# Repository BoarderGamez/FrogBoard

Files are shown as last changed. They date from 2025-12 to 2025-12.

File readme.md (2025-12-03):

# FrogBoard
My own devboard, from keyboard, to devboard 👍






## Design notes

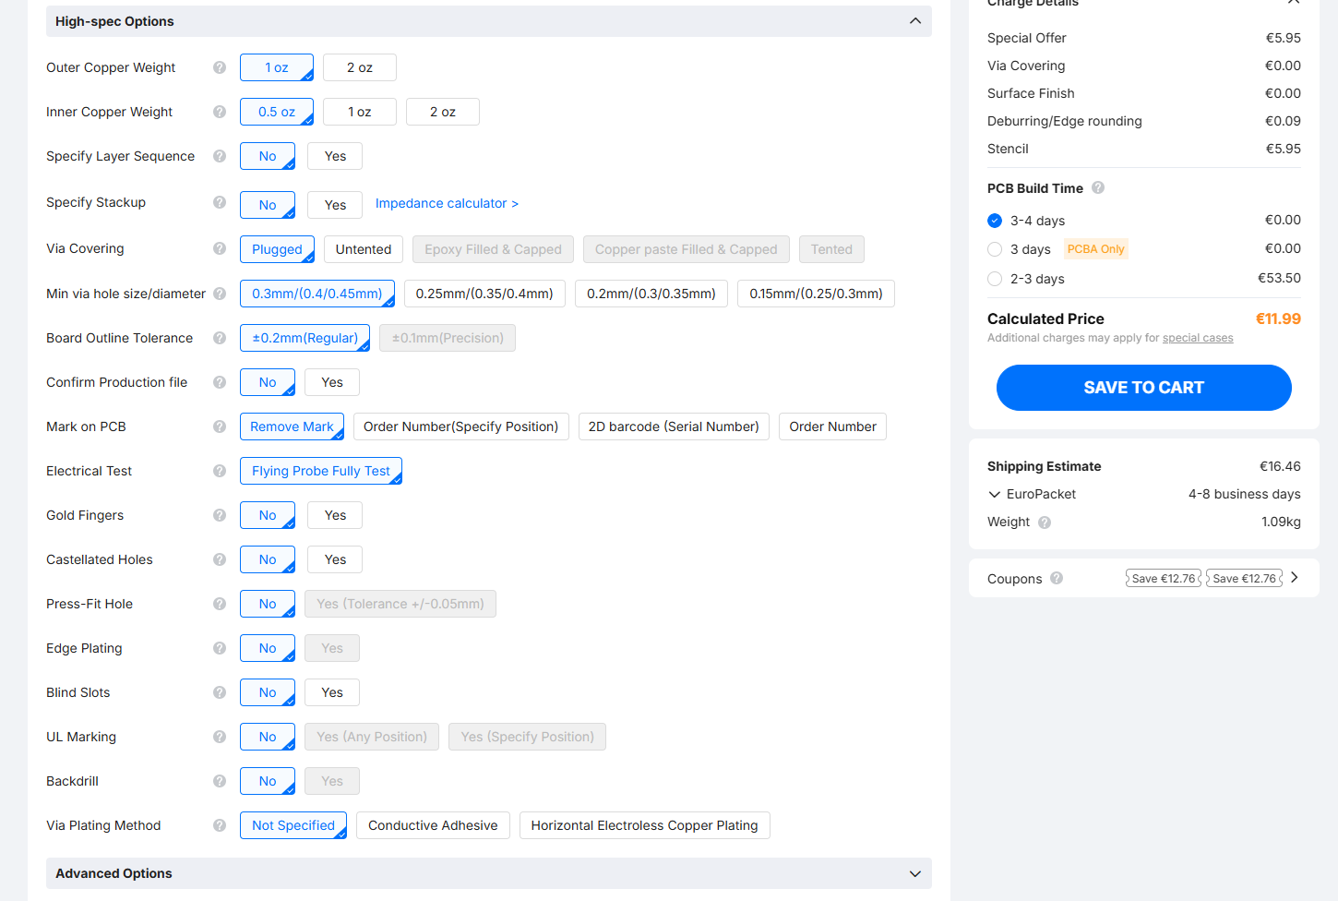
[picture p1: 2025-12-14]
pics/Screenshot 2025-12-14 181616.png

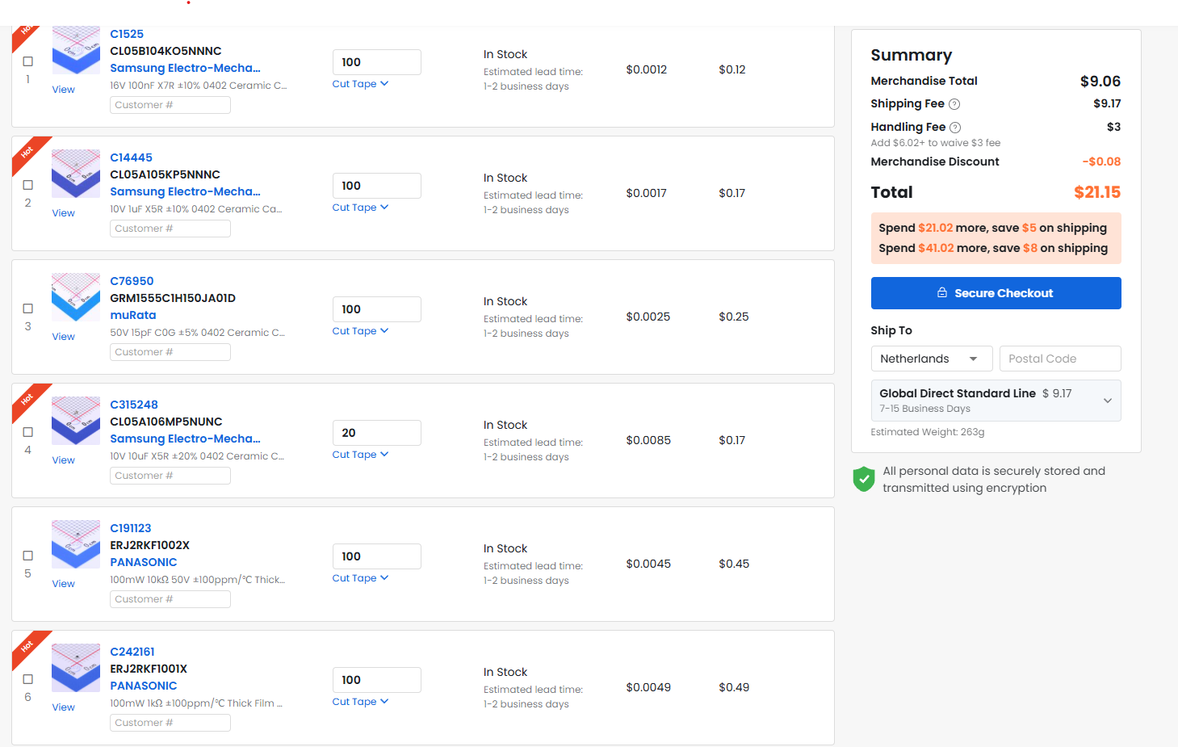
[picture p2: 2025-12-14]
pics/Screenshot 2025-12-14 181058.png

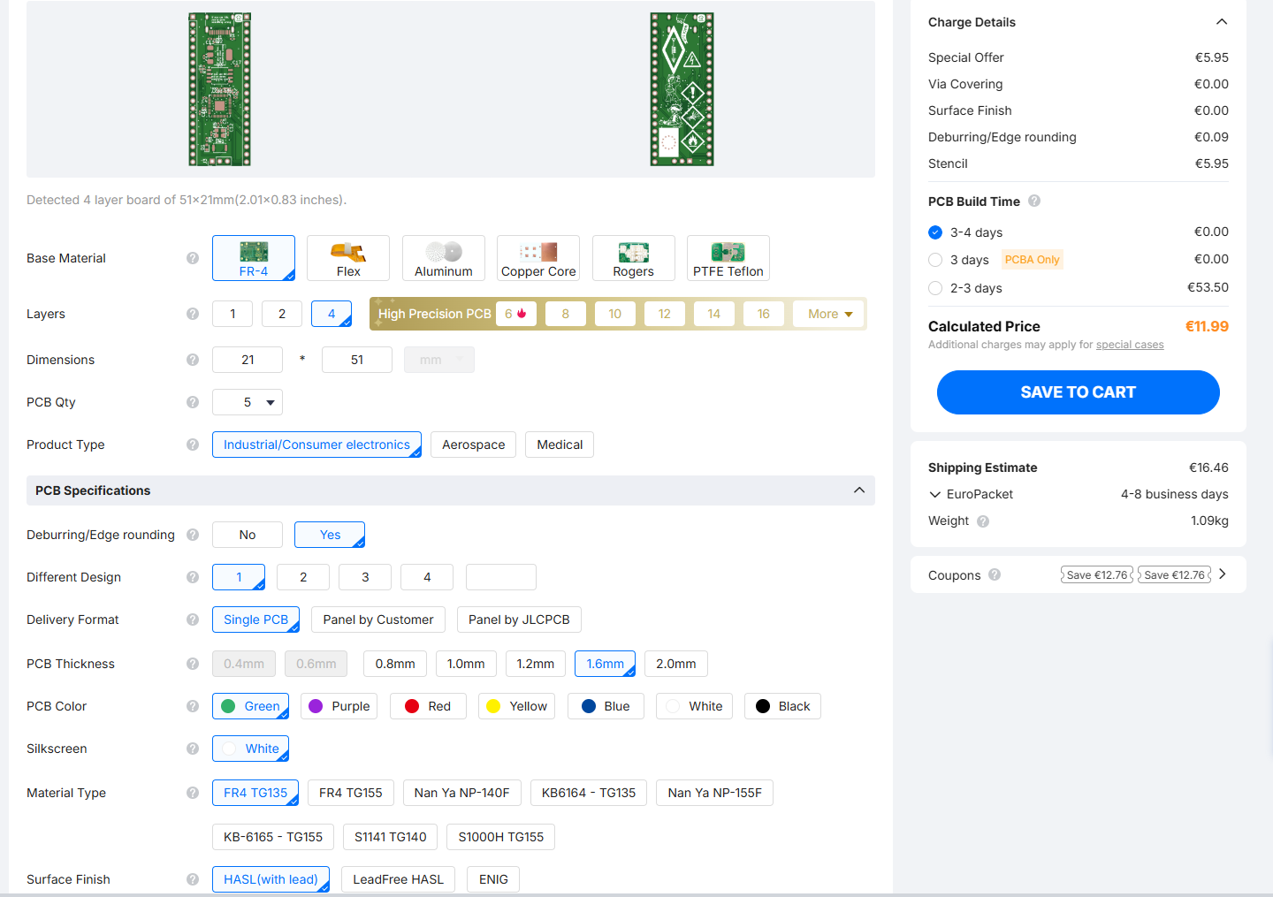
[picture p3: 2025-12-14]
pics/Screenshot 2025-12-14 181558.png

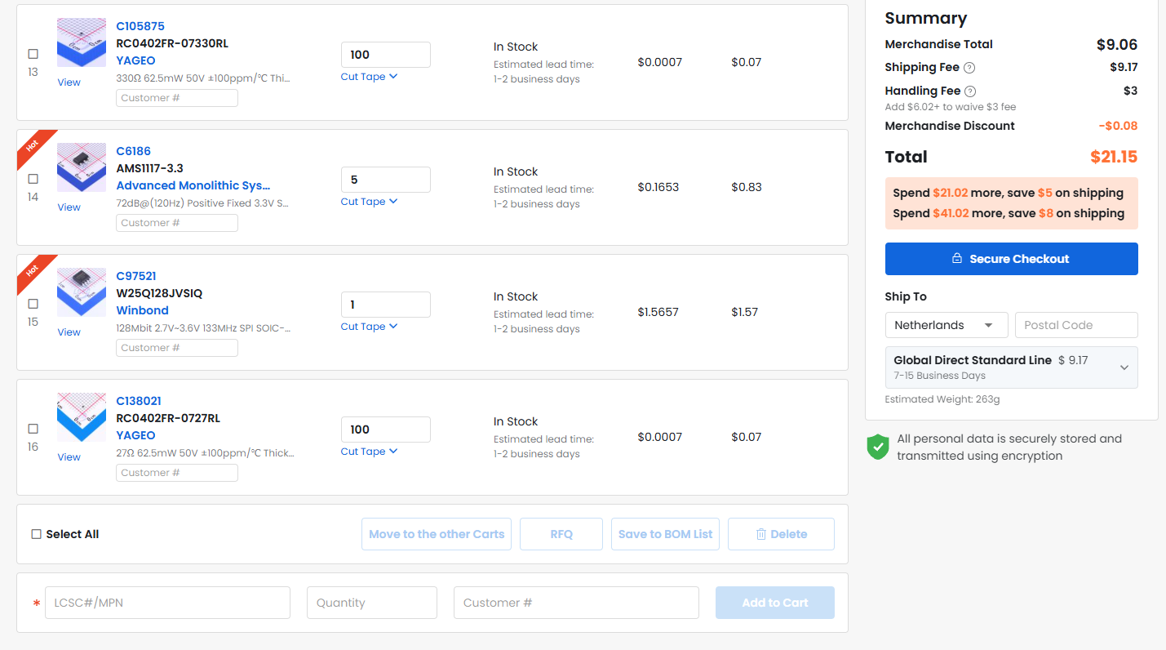
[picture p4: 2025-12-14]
pics/Screenshot 2025-12-14 181120.png

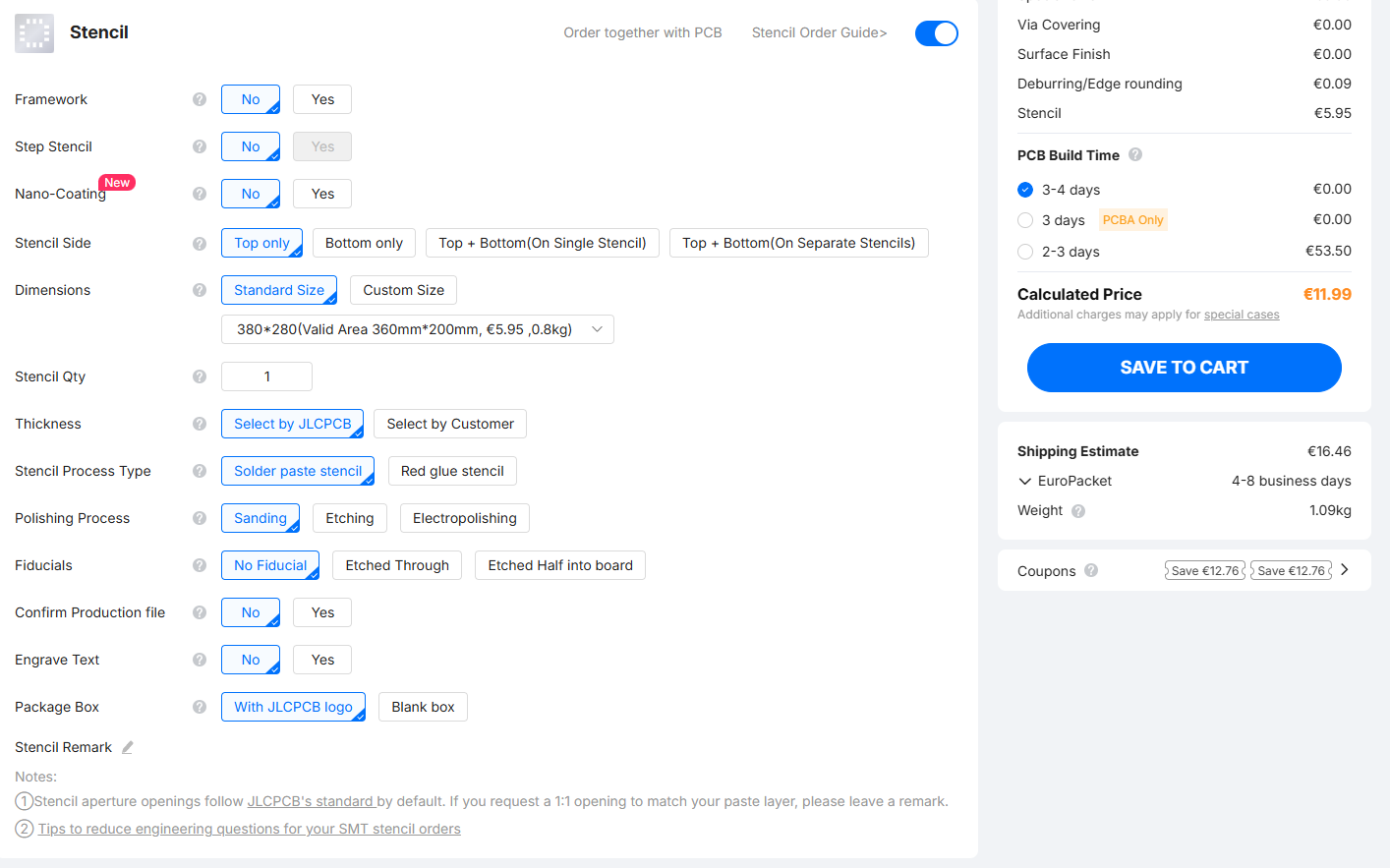
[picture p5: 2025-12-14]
pics/Screenshot 2025-12-14 181629.png

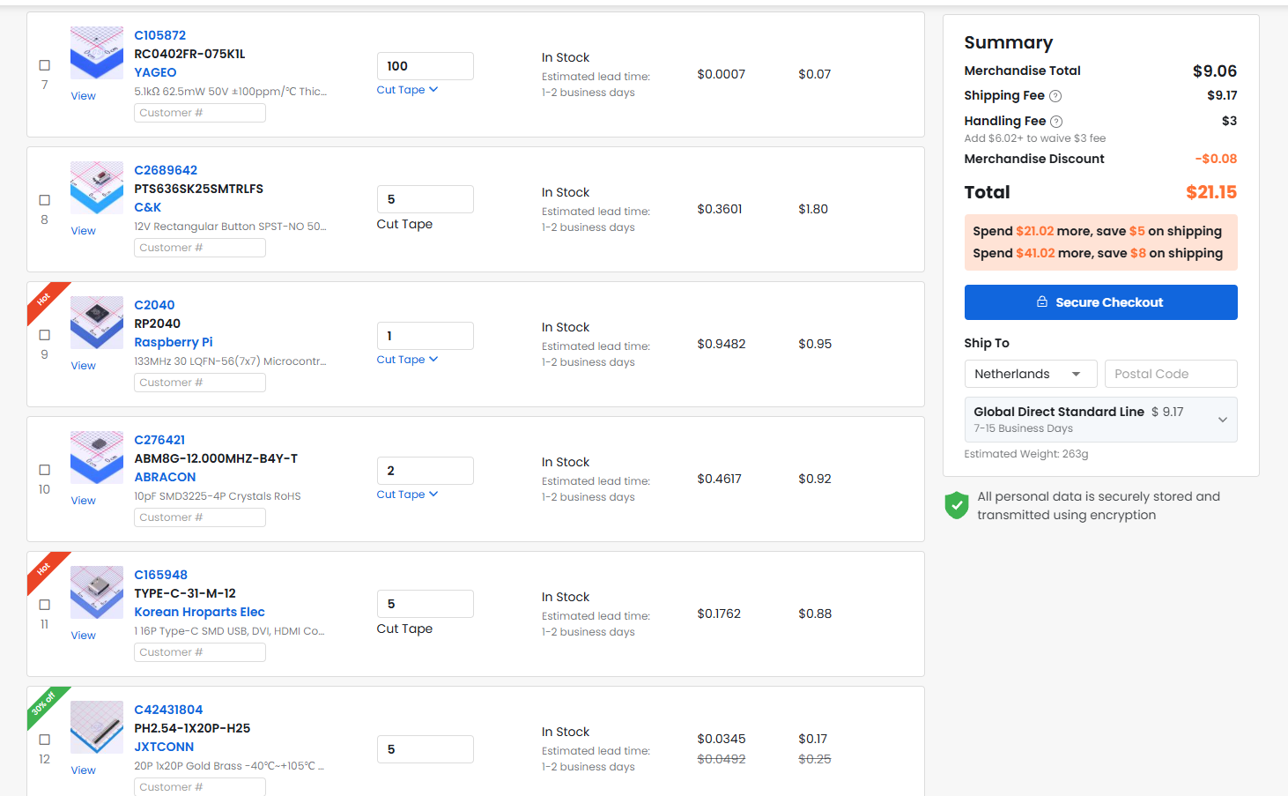
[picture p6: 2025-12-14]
pics/Screenshot 2025-12-14 181109.png

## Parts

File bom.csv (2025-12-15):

Index | LCSC# | MPN | Manufacturer | Package | Customer # | Description | RoHS | Quantity | MOQ | Multiple | Unit Price($) | Extended Price($) | Product Link | Total
1 | C1525 | CL05B104KO5NNNC | Samsung Electro-Mechanics | 0402 |  | 16V 100nF X7R ±10% 0402 Ceramic Capacitors RoHS | yes | 100 | 100 | 100 | 0.0012 | 0.12 | https://www.lcsc.com/product-detail/C1525.html | 0.12
2 | C14445 | CL05A105KP5NNNC | Samsung Electro-Mechanics | 0402 |  | 10V 1uF X5R ±10% 0402 Ceramic Capacitors RoHS | yes | 100 | 100 | 100 | 0.0017 | 0.17 | https://www.lcsc.com/product-detail/C14445.html | 0.29
3 | C76950 | GRM1555C1H150JA01D | muRata | 0402 |  | 50V 15pF C0G ±5% 0402 Ceramic Capacitors RoHS | yes | 100 | 100 | 100 | 0.0025 | 0.25 | https://www.lcsc.com/product-detail/C76950.html | 0.54
4 | C315248 | CL05A106MP5NUNC | Samsung Electro-Mechanics | 0402 |  | 10V 10uF X5R ±20% 0402 Ceramic Capacitors RoHS | yes | 20 | 20 | 20 | 0.0085 | 0.17 | https://www.lcsc.com/product-detail/C315248.html | 0.71
5 | C191123 | ERJ2RKF1002X | PANASONIC | 0402 |  | 100mW 10kΩ 50V ±100ppm/℃ Thick Film Resistor ±1% 0402 Chip Resistor - Surface Mount RoHS | yes | 100 | 100 | 100 | 0.0045 | 0.45 | https://www.lcsc.com/product-detail/C191123.html | 1.16
6 | C242161 | ERJ2RKF1001X | PANASONIC | 0402 |  | 100mW 1kΩ ±100ppm/℃ Thick Film Resistor ±1% 0402 Chip Resistor - Surface Mount RoHS | yes | 100 | 100 | 100 | 0.0049 | 0.49 | https://www.lcsc.com/product-detail/C242161.html | 1.65
7 | C105872 | RC0402FR-075K1L | YAGEO | 0402 |  | 5.1kΩ 62.5mW 50V ±100ppm/℃ Thick Film Resistor ±1% 0402 Chip Resistor - Surface Mount RoHS | yes | 100 | 100 | 100 | 0.0007 | 0.07 | https://www.lcsc.com/product-detail/C105872.html | 1.72
8 | C2689642 | PTS636SK25SMTRLFS | C&K | SMD,6x3.5mm |  | 12V Rectangular Button SPST-NO 50mA SMD,6x3.5mm Tactile Switches RoHS | yes | 5 | 5 | 5 | 0.3601 | 1.8 | https://www.lcsc.com/product-detail/C2689642.html | 3.52
9 | C2040 | RP2040 | Raspberry Pi | LQFN-56(7x7) |  | 133MHz 30 LQFN-56(7x7) Microcontrollers RoHS | yes | 1 | 1 | 1 | 0.9482 | 0.95 | https://www.lcsc.com/product-detail/C2040.html | 4.47
10 | C276421 | ABM8G-12.000MHZ-B4Y-T | ABRACON | SMD3225-4P |  | 10pF SMD3225-4P Crystals RoHS | yes | 2 | 1 | 1 | 0.4617 | 0.92 | https://www.lcsc.com/product-detail/C276421.html | 5.39
11 | C165948 | TYPE-C-31-M-12 | Korean Hroparts Elec | SMD |  | 1 16P Type-C SMD USB, DVI, HDMI Connector Assemblies RoHS | yes | 5 | 5 | 5 | 0.1762 | 0.88 | https://www.lcsc.com/product-detail/C165948.html | 6.27
12 | C42431804 | PH2.54-1X20P-H25 | JXTCONN | Through Hole,P=2.54mm |  | 20P 1x20P Gold Brass -40℃~+105℃ Pin Header Black 2.54mm 2.5mm 6mm 3mm 3A 1 Through Hole Through Hole,P=2.54mm Headers, Male Pins RoHS | yes | 5 | 5 | 5 | 0.0345 | 0.17 | https://www.lcsc.com/product-detail/C42431804.html | 6.44
13 | C105875 | RC0402FR-07330RL | YAGEO | 0402 |  | 330Ω 62.5mW 50V ±100ppm/℃ Thick Film Resistor ±1% 0402 Chip Resistor - Surface Mount RoHS | yes | 100 | 100 | 100 | 0.0007 | 0.07 | https://www.lcsc.com/product-detail/C105875.html | 6.51
14 | C6186 | AMS1117-3.3 | Advanced Monolithic Systems | SOT-223 |  | 72dB@(120Hz) Positive Fixed 3.3V SOT-223 Voltage Regulators - Linear, Low Drop Out (LDO) Regulators RoHS | yes | 5 | 5 | 5 | 0.1653 | 0.83 | https://www.lcsc.com/product-detail/C6186.html | 7.34
15 | C97521 | W25Q128JVSIQ | Winbond | SOIC-8-208mil |  | 128Mbit 2.7V~3.6V 133MHz SPI SOIC-8-208mil Memory (ICs) RoHS | yes | 1 | 1 | 1 | 1.5657 | 1.57 | https://www.lcsc.com/product-detail/C97521.html | 8.91
16 | C138021 | RC0402FR-0727RL | YAGEO | 0402 |  | 27Ω 62.5mW 50V ±100ppm/℃ Thick Film Resistor ±1% 0402 Chip Resistor - Surface Mount RoHS | yes | 100 | 100 | 100 | 0.0007 | 0.07 | https://www.lcsc.com/product-detail/C138021.html | 8.98
17 | Shipping |  |  | global direct |  |  |  |  |  |  |  | 12.17 |  | 21.15
18 | JLCPCB |  |  |  |  |  |  |  |  |  |  | 6.04 |  | 27.19
19 | Shipping |  |  | global direct |  | cheapest |  |  |  |  |  | 6.51 |  | 33.7
20 | customs |  |  | not cheap |  | not cheap |  |  |  |  |  | 2.85 |  | 36.55

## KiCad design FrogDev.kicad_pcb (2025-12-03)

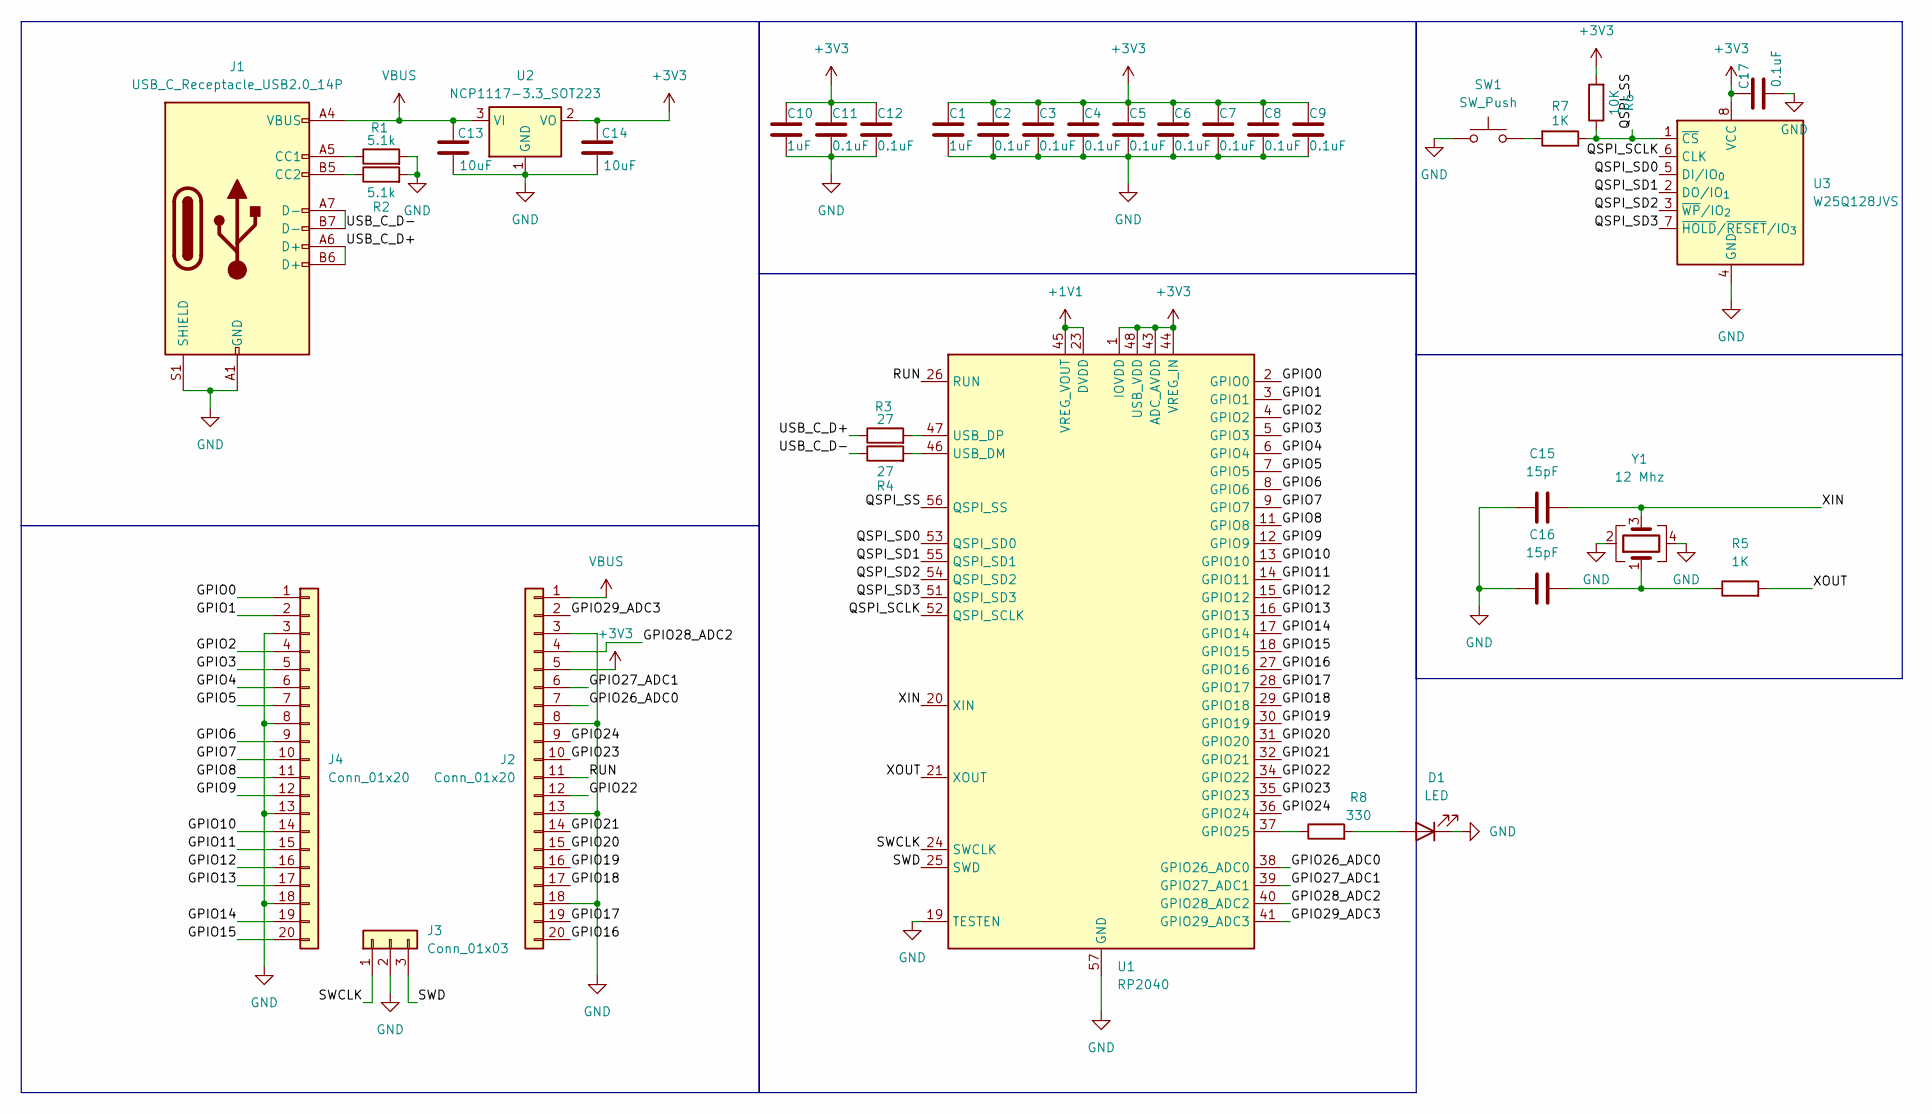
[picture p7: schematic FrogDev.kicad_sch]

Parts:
C1, C10: 1uF; C_0402_1005Metric
C2, C3, C4, C5, C6, C7, C8, C9, C11, C12, C17: 0.1uF; C_0402_1005Metric
C13, C14: 10uF; C_0402_1005Metric
C15, C16: 15pF; C_0402_1005Metric
D1: LED; LED_0603_1608Metric
J1: USB_C_Receptacle_USB2.0_14P; USB_C_Receptacle_HRO_TYPE-C-31-M-12
J2, J4: Conn_01x20; PinHeader_1x20_P2.54mm_Vertical
J3: Conn_01x03; PinHeader_1x03_P2.54mm_Vertical
R1, R2: 5.1k; R_0402_1005Metric
R3, R4: 27; R_0402_1005Metric
R5, R7: 1K; R_0402_1005Metric
R6: 10K; R_0402_1005Metric
R8: 330; R_0402_1005Metric
SW1: SW_Push; SW_Push_SPST_NO_Alps_SKRK
U1: RP2040; QFN-56-1EP_7x7mm_P0.4mm_EP3.2x3.2mm
U2: NCP1117-3.3_SOT223; SOT-223-3_TabPin2
U3: W25Q128JVS; SOIC-8_5.3x5.3mm_P1.27mm
Y1: 12 Mhz; Crystal_SMD_3225-4Pin_3.2x2.5mm

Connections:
+1V1: U1.23 (DVDD), U1.45 (VREG_VOUT), U1.50 (DVDD)
+3V3: C1.1, C2.1, C3.1, C4.1, C5.1, C6.1, C7.1, C8.1, C9.1, C10.1, C11.1, C12.1, C14.1, C17.1, J2.5, R6.2, U1.1 (IOVDD), U1.10 (IOVDD), U1.22 (IOVDD), U1.33 (IOVDD), U1.42 (IOVDD), U1.43 (ADC_AVDD), U1.44 (VREG_IN), U1.48 (USB_VDD), U1.49 (IOVDD), U2.2 (VO), U3.8 (VCC)
/GPIO0: J4.1, U1.2 (GPIO0)
/GPIO1: J4.2, U1.3 (GPIO1)
/GPIO2: J4.4, U1.4 (GPIO2)
/GPIO3: J4.5, U1.5 (GPIO3)
/GPIO4: J4.6, U1.6 (GPIO4)
/GPIO5: J4.7, U1.7 (GPIO5)
/GPIO6: J4.9, U1.8 (GPIO6)
/GPIO7: J4.10, U1.9 (GPIO7)
/GPIO8: J4.11, U1.11 (GPIO8)
/GPIO9: J4.12, U1.12 (GPIO9)
/GPIO10: J4.14, U1.13 (GPIO10)
/GPIO11: J4.15, U1.14 (GPIO11)
/GPIO12: J4.16, U1.15 (GPIO12)
/GPIO13: J4.17, U1.16 (GPIO13)
/GPIO14: J4.19, U1.17 (GPIO14)
/GPIO15: J4.20, U1.18 (GPIO15)
/GPIO16: J2.20, U1.27 (GPIO16)
/GPIO17: J2.19, U1.28 (GPIO17)
/GPIO18: J2.17, U1.29 (GPIO18)
/GPIO19: J2.16, U1.30 (GPIO19)
/GPIO20: J2.15, U1.31 (GPIO20)
/GPIO21: J2.14, U1.32 (GPIO21)
/GPIO22: J2.12, U1.34 (GPIO22)
/GPIO23: J2.10, U1.35 (GPIO23)
/GPIO24: J2.9, U1.36 (GPIO24)
/GPIO26_ADC0: J2.7, U1.38 (GPIO26_ADC0)
/GPIO27_ADC1: J2.6, U1.39 (GPIO27_ADC1)
/GPIO28_ADC2: J2.4, U1.40 (GPIO28_ADC2)
/GPIO29_ADC3: J2.2, U1.41 (GPIO29_ADC3)
/QSPI_SCLK: U1.52 (QSPI_SCLK), U3.6 (CLK)
/QSPI_SD0: U1.53 (QSPI_SD0), U3.5 (DI/IO_{0})
/QSPI_SD1: U1.55 (QSPI_SD1), U3.2 (DO/IO_{1})
/QSPI_SD2: U1.54 (QSPI_SD2), U3.3 (~WP/IO_{2})
/QSPI_SD3: U1.51 (QSPI_SD3), U3.7 (~HOLD/~RESET/IO_{3})
/QSPI_SS: R6.1, R7.1, U1.56 (QSPI_SS), U3.1 (~CS)
/RUN: J2.11, U1.26 (RUN)
/SWCLK: J3.1, U1.24 (SWCLK)
/SWD: J3.3, U1.25 (SWD)
/USB_C_D+: J1.A6 (D+), J1.B6 (D+), R3.1
/USB_C_D-: J1.A7 (D-), J1.B7 (D-), R4.1
/XIN: C15.2, U1.20 (XIN), Y1.3
/XOUT: R5.2, U1.21 (XOUT)
GND: C1.2, C2.2, C3.2, C4.2, C5.2, C6.2, C7.2, C8.2, C9.2, C10.2, C11.2, C12.2, C13.2, C14.2, C15.1, C16.1, C17.2, D1.1 (K), J1.A1 (GND), J1.A12 (GND), J1.B1 (GND), J1.B12 (GND), J1.S1 (SHIELD), J2.3, J2.8, J2.13, J2.18, J3.2, J4.3, J4.8, J4.13, J4.18, R1.2, R2.2, SW1.1, U1.19 (TESTEN), U1.57 (GND), U2.1 (GND), U3.4 (GND), Y1.2, Y1.4
unnamed: C16.2, R5.1, Y1.1
unnamed: D1.2 (A), R8.2
unnamed: J1.A5 (CC1), R1.1
unnamed: J1.B5 (CC2), R2.1
unnamed: R7.2, SW1.2
unnamed: R8.1, U1.37 (GPIO25)
unnamed: R4.2, U1.46 (USB_DM)
unnamed: R3.2, U1.47 (USB_DP)
VBUS: C13.1, J1.A4 (VBUS), J1.A9 (VBUS), J1.B4 (VBUS), J1.B9 (VBUS), J2.1, U2.3 (VI)

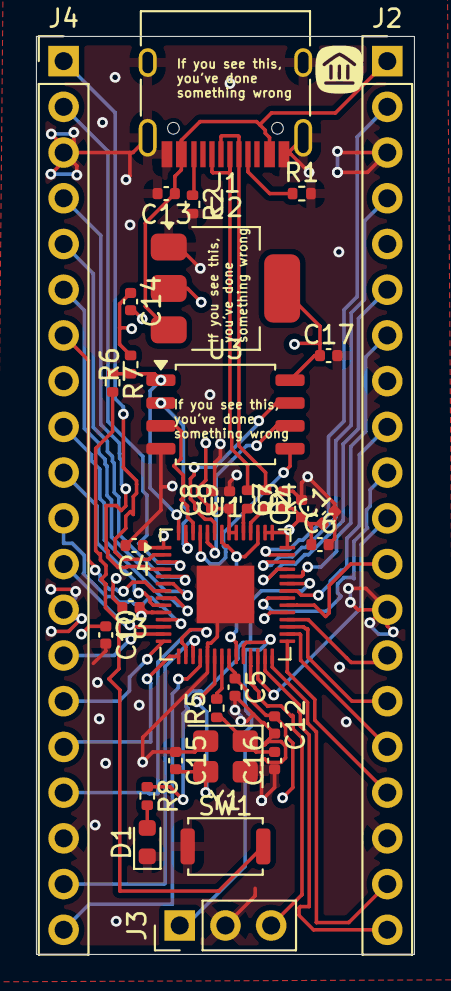
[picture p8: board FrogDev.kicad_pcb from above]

Board: 4 copper layers, 21.0 x 51.0 mm, 34 parts (0 on the bottom side), 54 nets.

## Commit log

2025-12-14 Update BOM with new entries and corrections
    [bom.csv]
2025-12-15 Revise BOM entries and fix formatting issues
    Updated the BOM file by replacing the old entries with new ones and correcting formatting issues.
    [bom.csv]
